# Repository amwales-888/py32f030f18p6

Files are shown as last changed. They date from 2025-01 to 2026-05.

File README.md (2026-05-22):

# py32f030f18p6
Simple breakout board for py32f030f18p6

- 3.3v LDO powered from 5V USB.
- UART connectivity to USB via ch340k optionally connected using jumpers.
- ARM SWD programming interface header.
- All other pins are broken out to headers.
- 1 LED optionally connected to pin PB5 using jumper.
- 1 Button optionally connected to pin PA8 using jumper.
- 1 Button connected to RESET pin, pulled high.
- Booloader selected by putting jumper across BOOT0 and 3v3 pins

<table>
  <tr>
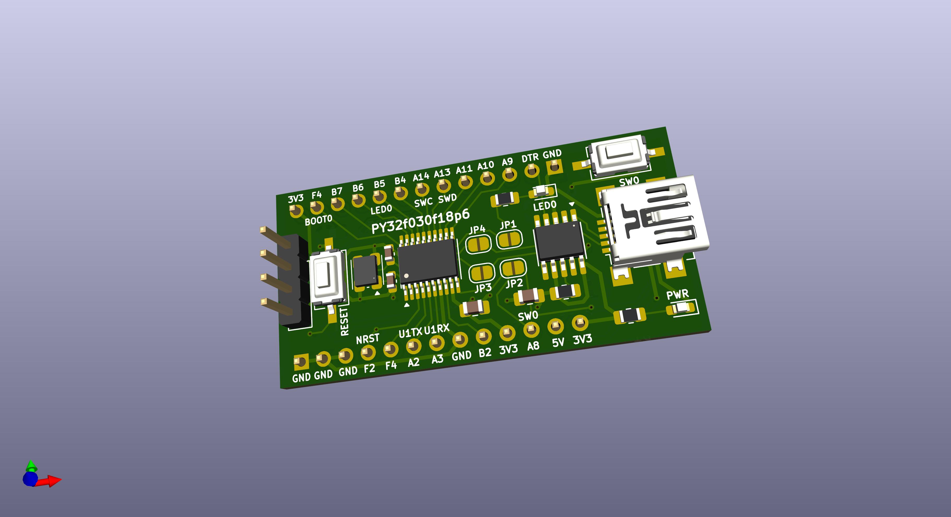
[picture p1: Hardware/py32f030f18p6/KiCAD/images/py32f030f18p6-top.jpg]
    <td> </td>
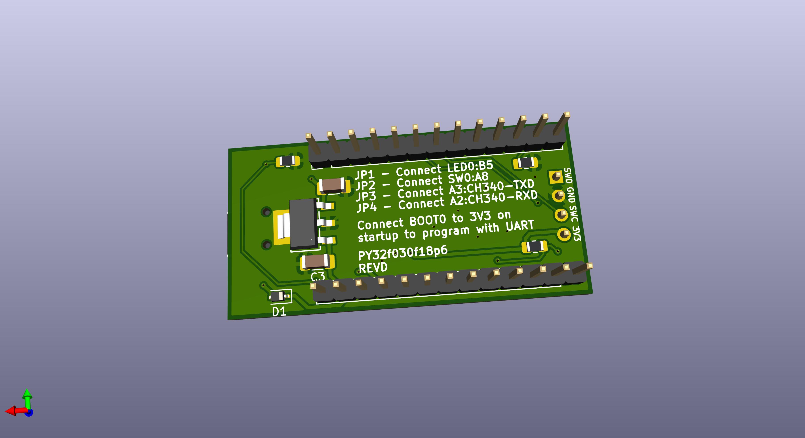
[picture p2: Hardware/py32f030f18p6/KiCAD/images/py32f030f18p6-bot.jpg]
    <td> </td>
  </tr>
  <tr>
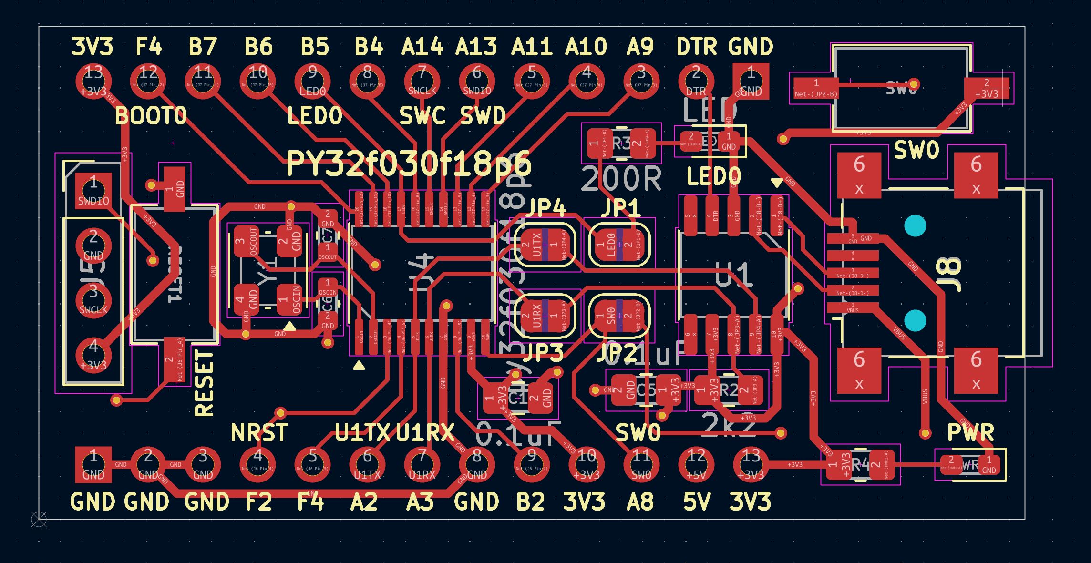
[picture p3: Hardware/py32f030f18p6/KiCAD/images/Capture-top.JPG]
    <td> </td>
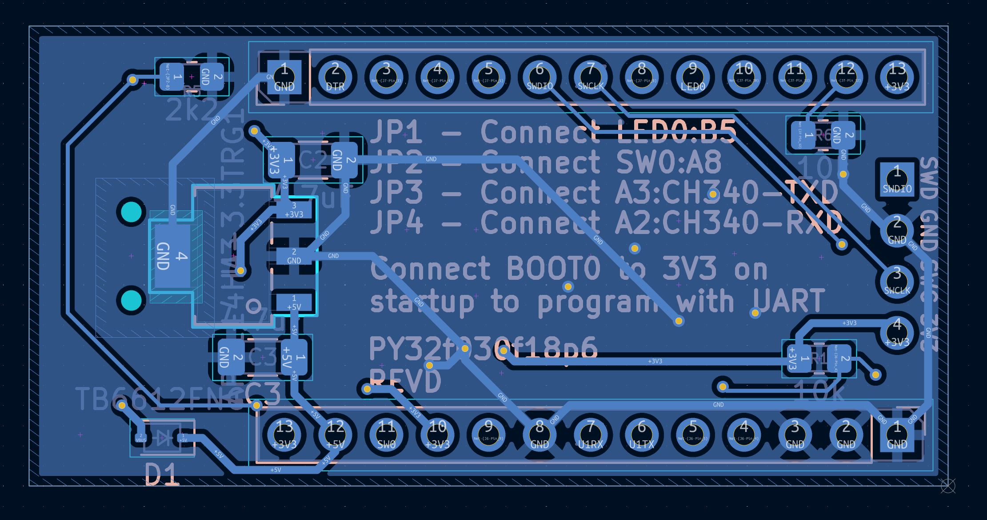
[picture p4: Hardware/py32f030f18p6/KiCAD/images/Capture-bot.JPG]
    <td> </td>
  </tr>
  <tr>
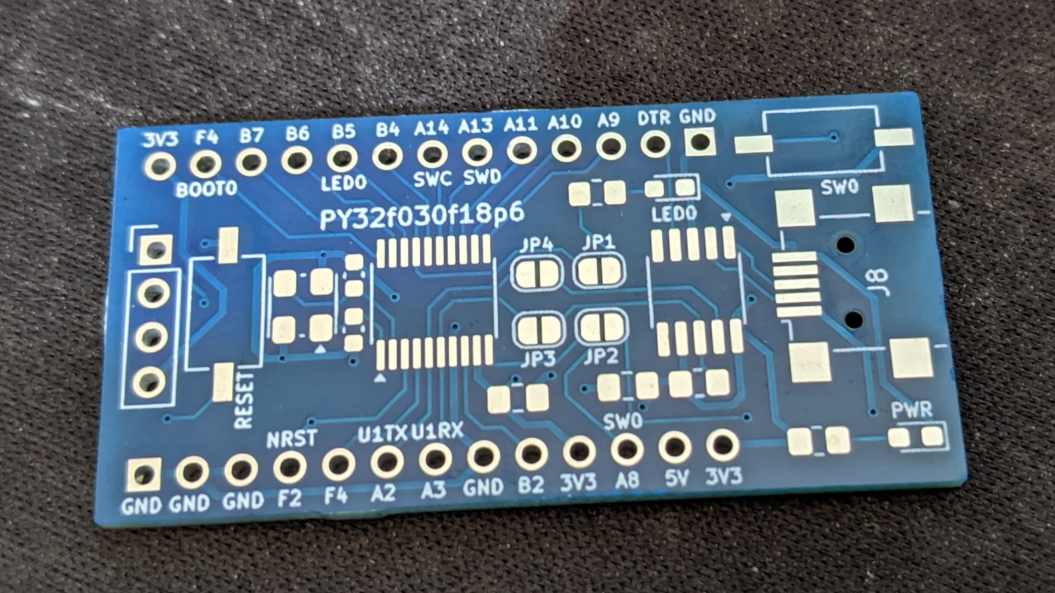
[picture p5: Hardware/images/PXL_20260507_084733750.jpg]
    <td> </td>
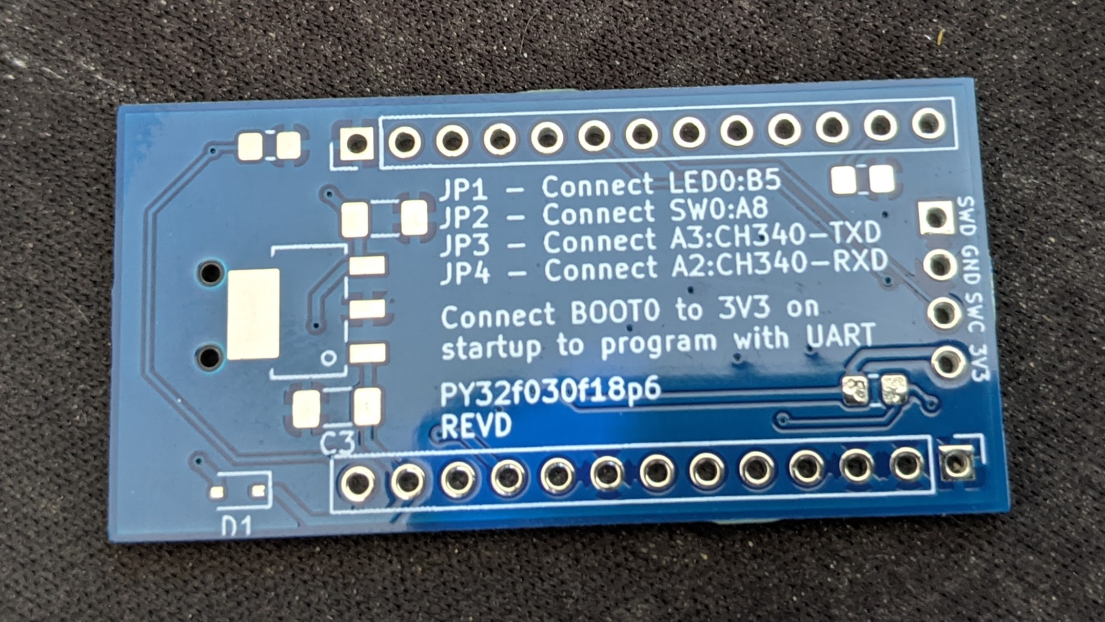
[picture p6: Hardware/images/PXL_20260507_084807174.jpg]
    <td> </td>
  </tr>
  <tr>
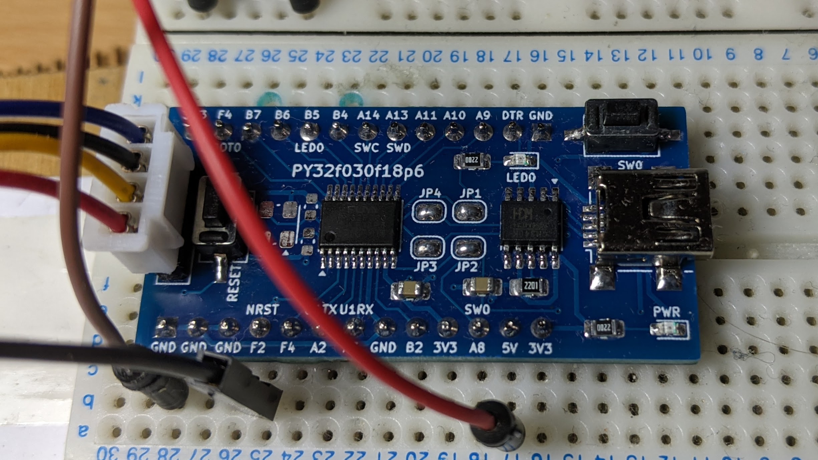
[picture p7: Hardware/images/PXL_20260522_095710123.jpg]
    <td> </td>
  </tr>
</table>

Resources

<li>https://www.puyasemi.com/en/py32_series.html</li>
<li>https://www.eevblog.com/forum/microcontrollers/$0-11-py32f002a-m0-24mhz-320kb-actually-324kb-more-peripherals/</li>
<li>https://www.cnblogs.com/milton/p/18168592</li>
<li>https://github.com/IOsetting/py32f0-template/tree/main</li>
<li>https://www.cnblogs.com/milton/p/17111286.html</li>
<li>https://www.cnblogs.com/milton/p/18168592</li>
<li>https://www.lcsc.com/product-detail/C3018715.html</li>

<BR>

Notes - Assembled board with 24Mhz crystal, flashed and tested with simple LED blink/UART code via the connected via USB. Used jlink clone connected via SWD and built with keil uvision, connected jlink to reset pin. Verified running at 48Mhz by timing blink rate of LED. Have not tested bootloader configuration yet.

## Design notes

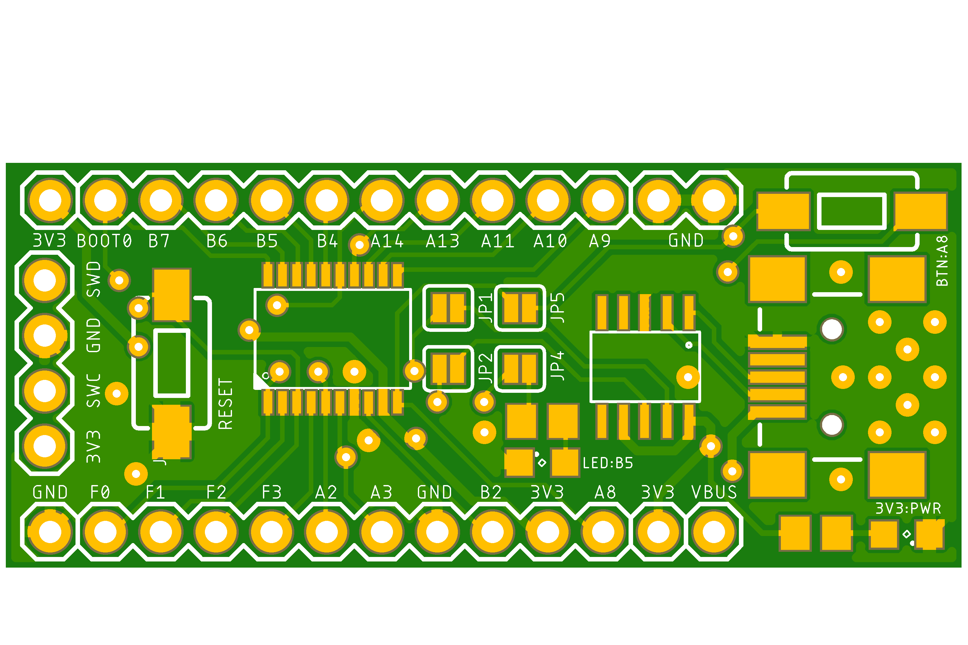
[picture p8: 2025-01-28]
Hardware/py32f030f18p6/Eagle/images/py32f030f18p6-Top.png

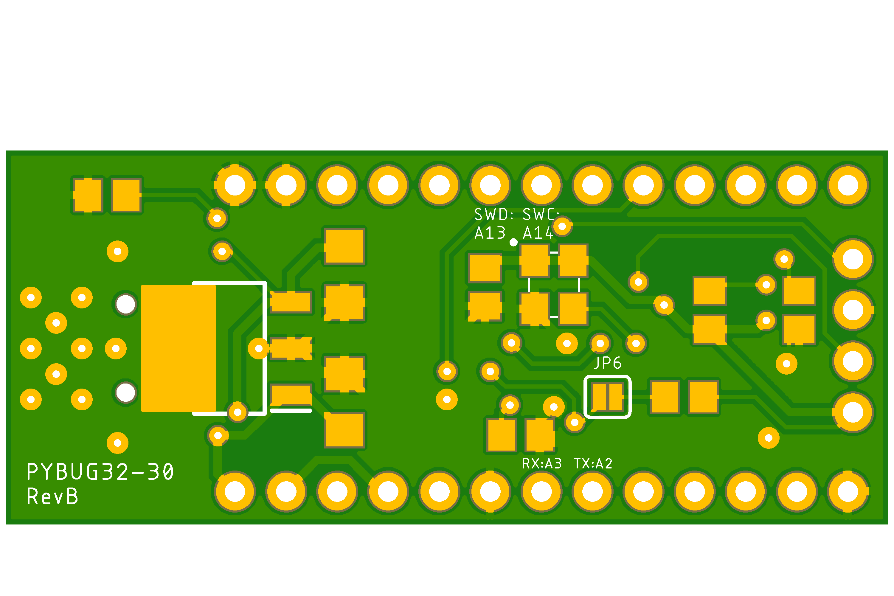
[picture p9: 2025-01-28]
Hardware/py32f030f18p6/Eagle/images/py32f030f18p6-Bot.png

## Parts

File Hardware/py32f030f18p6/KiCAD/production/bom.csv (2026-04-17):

Designator | Footprint | Quantity | Value | LCSC Part #
C1, C5 | 0805 | 2 | 0.1uF
C2, C3 | 1206 | 2 | 4.7uF
C6, C7 | 0603 | 2 | 18pF
D1 | D_SOD-323 | 1 | TB6612FNG
J5 | PinHeader_1x04_P2.54mm_Vertical | 1 | Conn_01x04_Pin
J6, J7 | PinHeader_1x13_P2.54mm_Vertical | 2 | Conn_01x13_Pin
J8 | USB_Mini-B_Lumberg_2486_01_Horizontal | 1 | USB_B_Mini
LED0, PWR1 | 0603 | 2 | LED
R1, R6 | 0805 | 2 | 10k
R2, R5 | 0805 | 2 | 2k2
R3, R4 | 0805 | 2 | 200R
RESET1, SW0 | SW_Tactile_SPST_NO_Straight_CK_PTS636Sx25SMTRLFS | 2 | SW_Push
U1 | SSOP-10-1EP_3.9x4.9mm_P1mm_EP2.1x3.3mm | 1 | CH340K
U3 | SOT-223_DIO | 1 | AP2114HA-3.3TRG1
U4 | TSSOP-20_4.4x6.5mm_P0.65mm | 1 | py32f030f18p6
Y1 | CDFN-4_2.5x3.2mm_P2.1mm | 1 | 16Mhz Crystal

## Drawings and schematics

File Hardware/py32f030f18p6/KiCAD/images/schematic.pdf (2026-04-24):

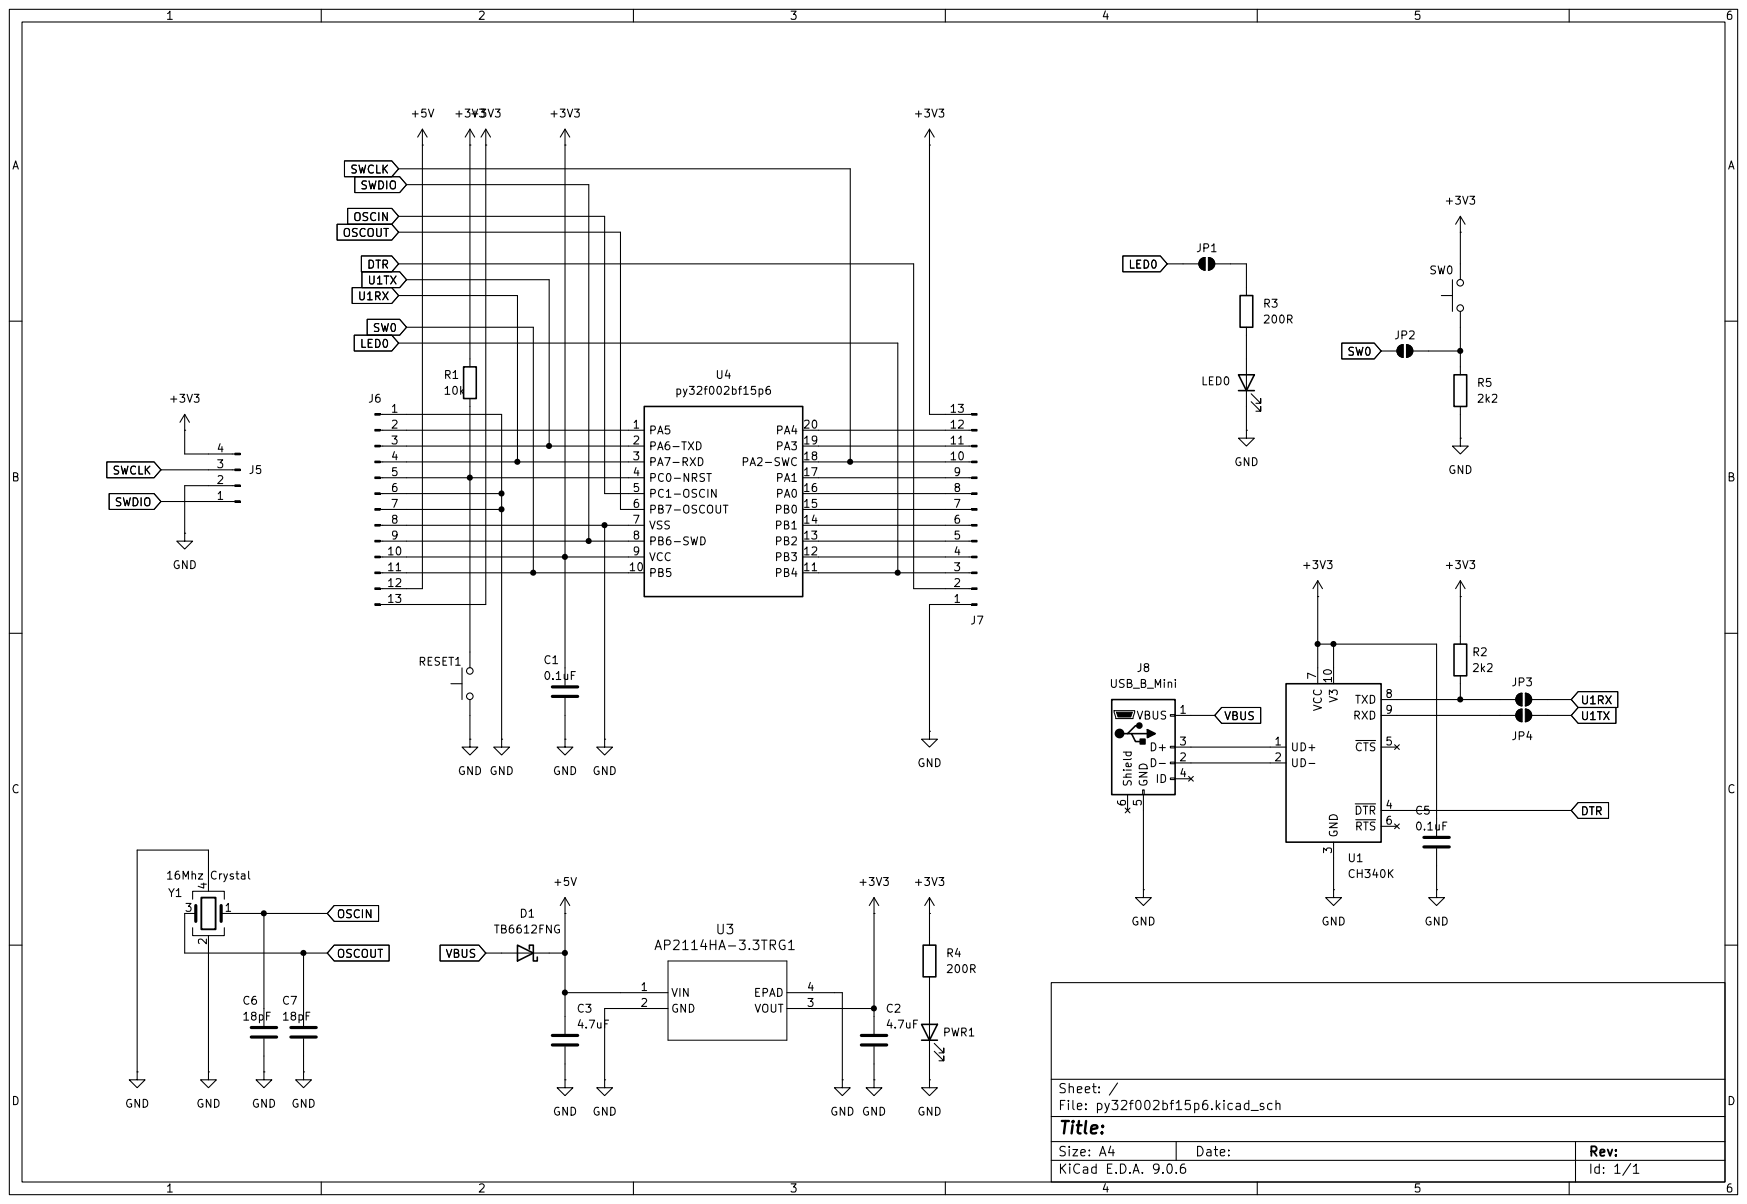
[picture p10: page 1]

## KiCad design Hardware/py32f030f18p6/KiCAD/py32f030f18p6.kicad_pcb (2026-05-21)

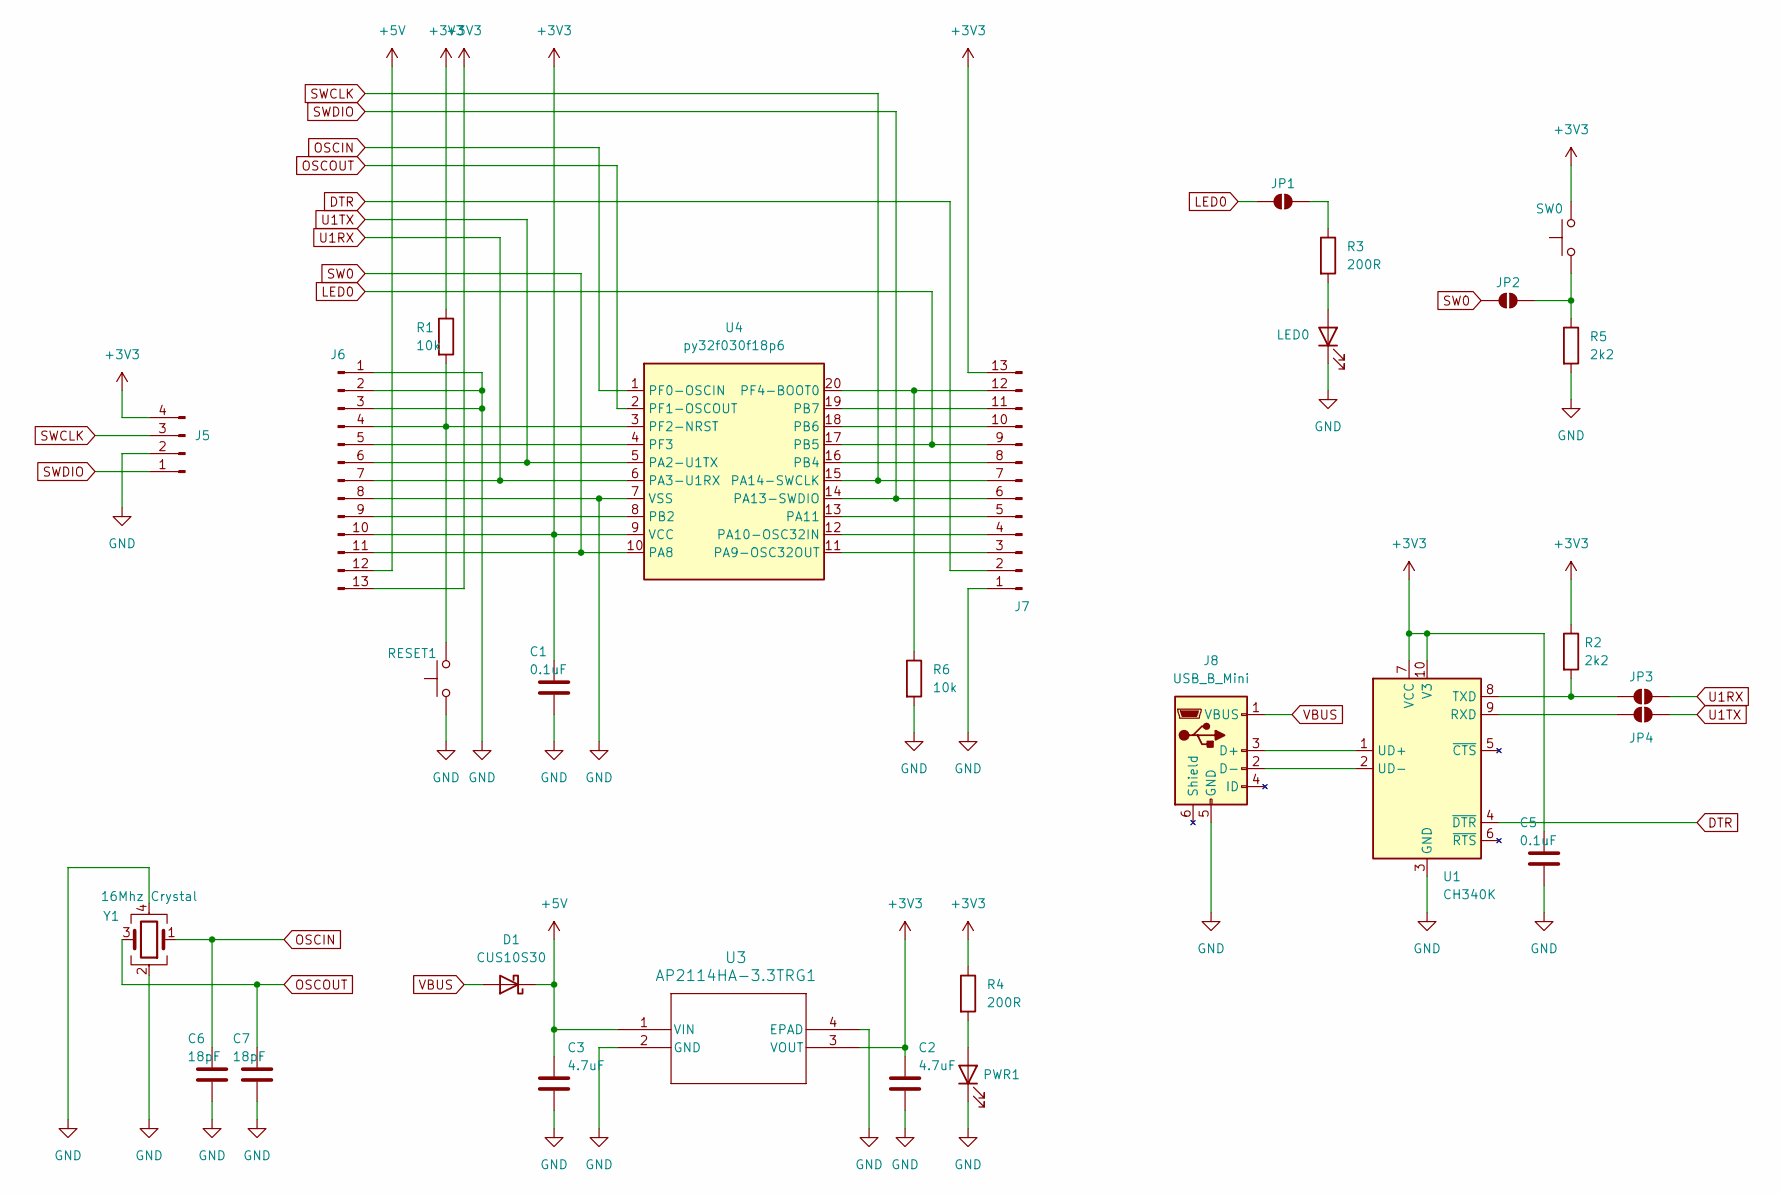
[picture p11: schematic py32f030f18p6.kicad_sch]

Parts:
C1, C5: 0.1uF; C_0805_2012Metric_Pad1.18x1.45mm_HandSolder
C2, C3: 4.7uF; C_1206_3216Metric_Pad1.33x1.80mm_HandSolder
C6, C7: 18pF; C_0603_1608Metric
D1: CUS10S30; D_SOD-323-H; LCSC Part# C146335
J5: Conn_01x04_Pin; PinHeader_1x04_P2.54mm_Vertical
J6, J7: Conn_01x13_Pin; PinHeader_1x13_P2.54mm_Vertical
J8: USB_B_Mini; USB_Mini-B_Lumberg_2486_01_Horizontal; LCSC Part# C105424
JP1, JP2, JP3, JP4: SolderJumper_2_Open; SolderJumper-2_P1.3mm_Open_RoundedPad1.0x1.5mm
LED0: LED; LED_0603_1608Metric_Pad1.05x0.95mm_HandSolder
PWR1: LED; LED_0603_1608Metric_Pad1.05x0.95mm_HandSolder
R1, R6: 10k; R_0805_2012Metric_Pad1.20x1.40mm_HandSolder
R2, R5: 2k2; R_0805_2012Metric_Pad1.20x1.40mm_HandSolder
R3, R4: 200R; R_0805_2012Metric_Pad1.20x1.40mm_HandSolder
RESET1: SW_Push; SW_Tactile_SPST_NO_Straight_CK_PTS636Sx25SMTRLFS
SW0: SW_Push; SW_Tactile_SPST_NO_Straight_CK_PTS636Sx25SMTRLFS
U1: CH340K; SSOP-10-1EP_3.9x4.9mm_P1mm_EP2.1x3.3mm; LCSC Part# C968586
U3: AP2114HA-3.3TRG1; SOT-223_DIO; LCSC Part# C460314
U4: py32f030f18p6; TSSOP-20_4.4x6.5mm_P0.65mm; LCSC Part# C3018715
Y1: 16Mhz Crystal; CDFN-4_2.5x3.2mm_P2.1mm; LCSC Part# C41383242

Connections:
+3V3: C1.1, C2.1, C5.1, J5.4, J6.10, J6.13, J7.13, R1.1, R2.1, R4.1, SW0.2, U1.7 (VCC), U1.10 (V3), U3.3 (VOUT), U4.9 (VCC)
+5V: C3.1, D1.1 (K), J6.12, U3.1 (VIN)
DTR: J7.2, U1.4 (~DTR)
GND: C1.2, C2.2, C3.2, C5.2, C6.2, C7.2, J5.2, J6.1, J6.2, J6.3, J6.8, J7.1, J8.5 (GND), LED0.1 (K), PWR1.1 (K), R5.2, R6.2, RESET1.1, U1.3 (GND), U3.2 (GND), U3.4 (EPAD), U4.7 (VSS), Y1.2, Y1.4
LED0: J7.9, JP1.1 (A), U4.17 (PB5)
unnamed: J6.4, R1.2, RESET1.2, U4.3 (PF2-NRST)
unnamed: J6.5, U4.4 (PF3)
unnamed: J6.9, U4.8 (PB2)
unnamed: J7.3, U4.11 (PA9-OSC32OUT)
unnamed: J7.4, U4.12 (PA10-OSC32IN)
unnamed: J7.5, U4.13 (PA11)
unnamed: J7.8, U4.16 (PB4)
unnamed: J7.10, U4.18 (PB6)
unnamed: J7.11, U4.19 (PB7)
unnamed: J7.12, R6.1, U4.20 (PF4-BOOT0)
unnamed: J8.3 (D+), U1.1 (UD+)
unnamed: J8.2 (D-), U1.2 (UD-)
unnamed: JP1.2 (B), R3.1
unnamed: JP2.2 (B), R5.1, SW0.1
unnamed: JP3.1 (A), R2.2, U1.8 (TXD)
unnamed: JP4.1 (A), U1.9 (RXD)
unnamed: LED0.2 (A), R3.2
unnamed: PWR1.2 (A), R4.2
OSCIN: C6.1, U4.1 (PF0-OSCIN), Y1.1
OSCOUT: C7.1, U4.2 (PF1-OSCOUT), Y1.3
SW0: J6.11, JP2.1 (A), U4.10 (PA8)
SWCLK: J5.3, J7.7, U4.15 (PA14-SWCLK)
SWDIO: J5.1, J7.6, U4.14 (PA13-SWDIO)
U1RX: J6.7, JP3.2 (B), U4.6 (PA3-U1RX)
U1TX: J6.6, JP4.2 (B), U4.5 (PA2-U1TX)
VBUS: D1.2 (A), J8.1 (VBUS)

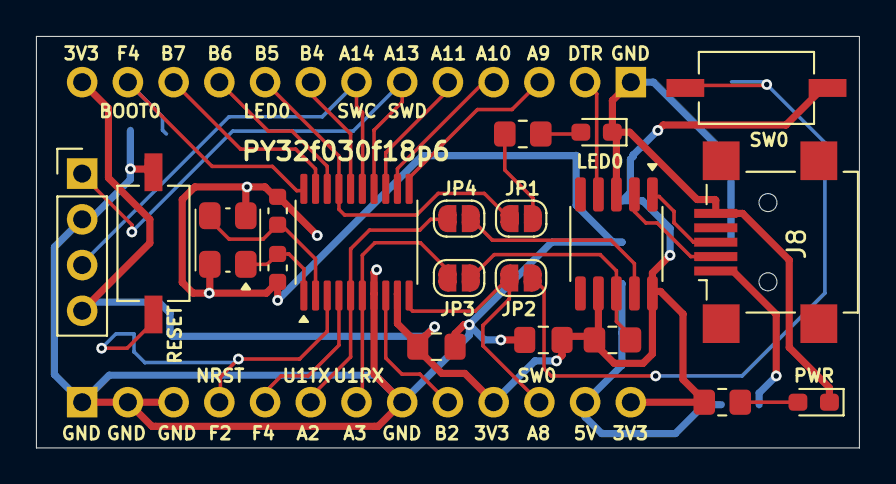
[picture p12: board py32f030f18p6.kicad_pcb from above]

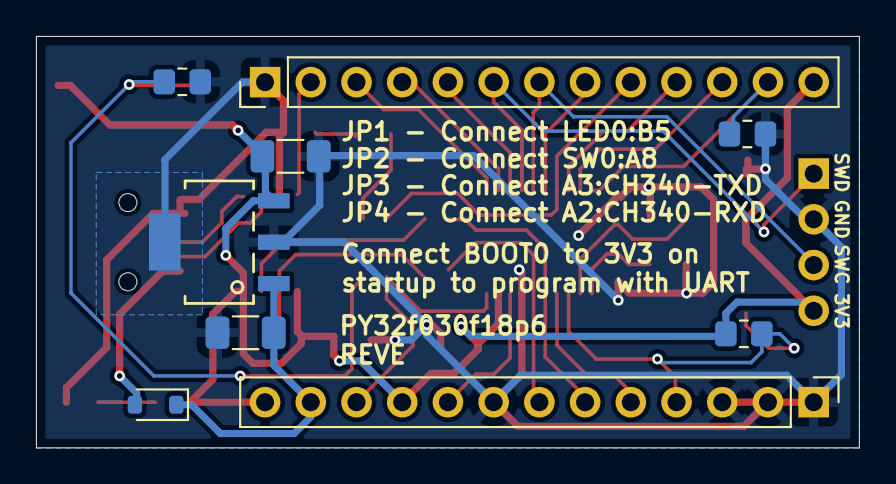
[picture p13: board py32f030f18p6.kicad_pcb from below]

Board: 2 copper layers, 45.7 x 22.9 mm, 29 parts (9 on the bottom side), 31 nets.

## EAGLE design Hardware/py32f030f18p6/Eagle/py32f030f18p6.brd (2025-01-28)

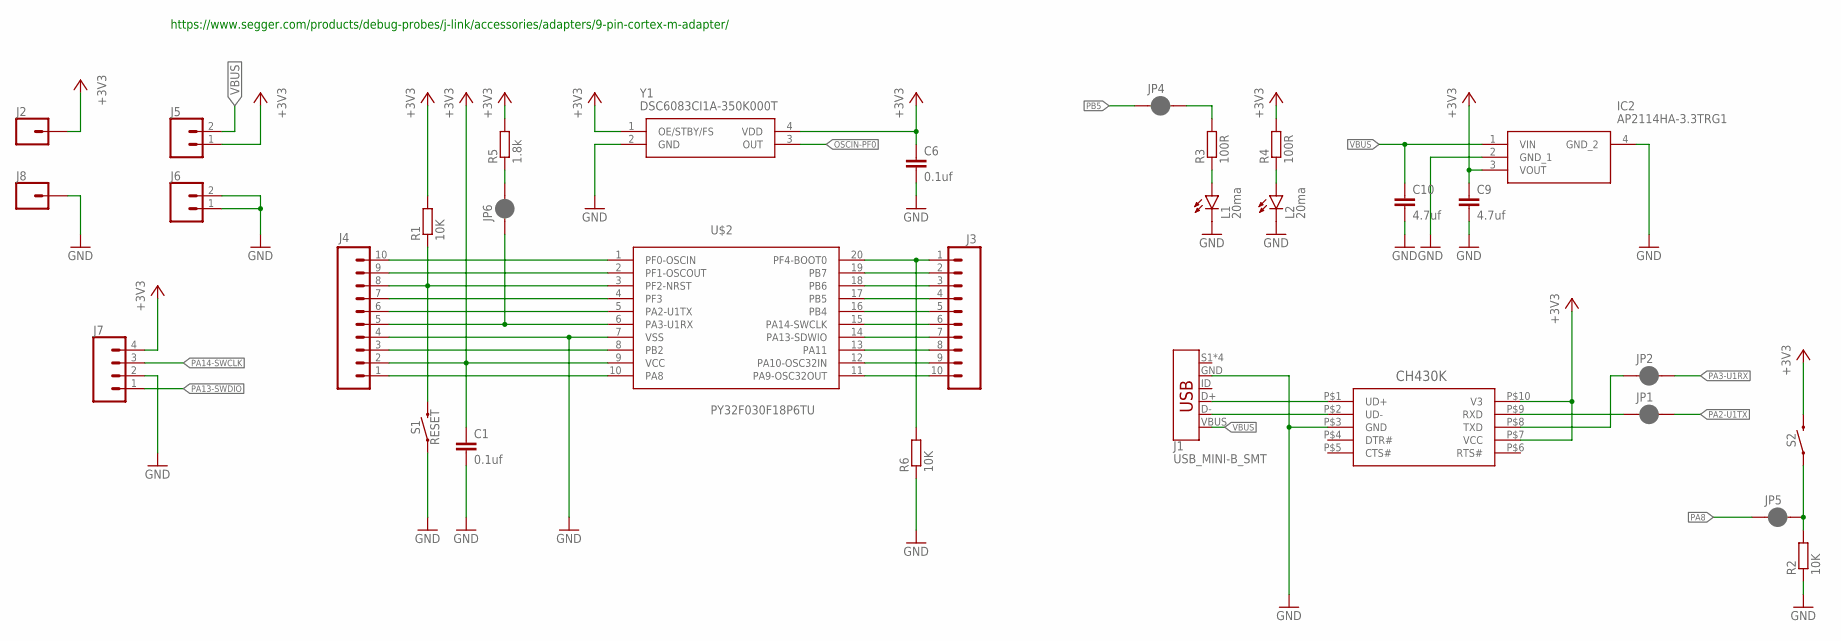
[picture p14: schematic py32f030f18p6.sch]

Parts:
C1, C6: 0.1uf; C0805
C9, C10: 4.7uf; C1206
IC2: AP2114HA-3.3TRG1; SOT230P700X180-4N
J1: USB_MINI-B_SMT; USB-MINIB
J2, J8: CONN_01; 1X01
J3, J4: CONN_10"; 1X10
J5, J6: CONN_02; 1X02
J7: CONN_04PTH; 1X04
JP1, JP2, JP4, JP5, JP6: JUMPER-SMT_2_NC_PASTE_SILK; SMT-JUMPER_2_NC_PASTE_SILK
L1, L2: 20ma; SML0805
R1, R2, R6: 10K; R0805
R3, R4: 100R; R0805
R5: 1.8k; R0805
S1, S2: RESET; TACTILE_SWITCH_SMD_6.0X3.5MM
U$1: CH430K; ESSOP-10
U$2: PY32F030F18P6TU; TSSOP20
Y1: DSC6083CI1A-350K000T; DSC6083CI1A350K000T

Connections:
+3V3: C1.1, C6.1, C9.1, IC2.3 (VOUT), J2.1, J4.2, J5.1, J7.4, R1.2, R4.2, R5.2, S2.2, U$1.P$7 (VCC), U$1.P$10 (V3), U$2.9 (VCC), Y1.1 (OE/STBY/FS), Y1.4 (VDD)
GND: C1.2, C6.2, C9.2, C10.2, IC2.2 (GND_1), IC2.4 (GND_2), J1.GND, J4.4, J6.1, J6.2, J7.2, J8.1, L1.C, L2.C, R2.1, R6.1, S1.1, U$1.P$3 (GND), U$2.7 (VSS), Y1.2 (GND)
unnamed: JP6.2, R5.1
unnamed: L1.A, R3.1
unnamed: JP4.2, R3.2
unnamed: JP5.2, R2.2, S2.1
unnamed: L2.A, R4.1
OSCIN-PF0: J4.10, U$2.1 (PF0-OSCIN), Y1.3 (OUT)
OSCOUT-PF1: J4.9, U$2.2 (PF1-OSCOUT)
PA2-U1TX: J4.6, JP1.2, U$2.5 (PA2-U1TX)
PA3-U1RX: J4.5, JP2.2, JP6.1, U$2.6 (PA3-U1RX)
PA8: J4.1, JP5.1, U$2.10 (PA8)
PA9-OSC32OUT: J3.10, U$2.11 (PA9-OSC32OUT)
PA10-OSC32IN: J3.9, U$2.12 (PA10-OSC32IN)
PA11: J3.8, U$2.13 (PA11)
PA13-SWDIO: J3.7, J7.1, U$2.14 (PA13-SDWIO)
PA14-SWCLK: J3.6, J7.3, U$2.15 (PA14-SWCLK)
PB2: J4.3, U$2.8 (PB2)
PB4: J3.5, U$2.16 (PB4)
PB5: J3.4, JP4.1, U$2.17 (PB5)
PB6: J3.3, U$2.18 (PB6)
PB7: J3.2, U$2.19 (PB7)
PF2-NRST: J4.8, R1.1, S1.2, U$2.3 (PF2-NRST)
PF3: J4.7, U$2.4 (PF3)
PF4-BOOT0: J3.1, R6.2, U$2.20 (PF4-BOOT0)
RXD: JP1.1, U$1.P$9 (RXD)
TXD: JP2.1, U$1.P$8 (TXD)
USB_N: J1.D-, U$1.P$2 (UD-)
USB_P: J1.D+, U$1.P$1 (UD+)
VBUS: C10.1, IC2.1 (VIN), J1.VBUS, J5.2

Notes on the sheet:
https://www.segger.com/products/debug-probes/j-link/accessories/adapters/9-pin-cortex-m-adapter/

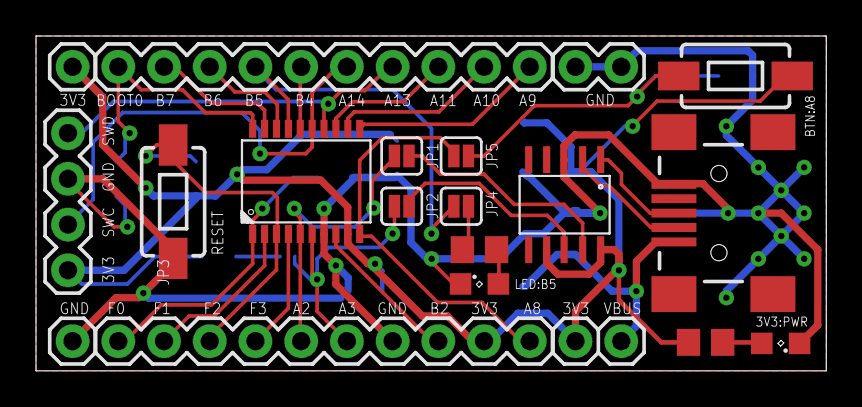
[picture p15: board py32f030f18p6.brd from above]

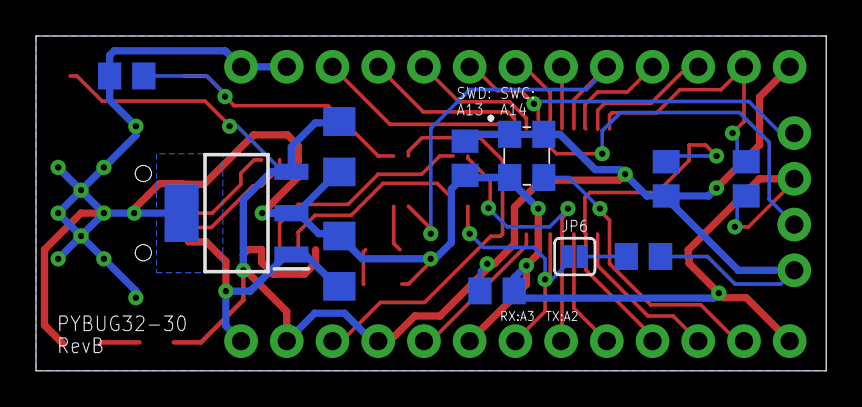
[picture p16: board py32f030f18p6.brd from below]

Board: 2 copper layers, 43.9 x 18.6 mm, 31 parts (11 on the bottom side), 30 nets.

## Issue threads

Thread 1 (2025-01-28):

Not really an issue ;-) ::   I would like to know if you build a test board successfully ?

demoze, 2025-01-28:
HEllo,

Not really an issue ;-)

I would like to know if you build a test board successfully ?

Regards

amwales-888, 2025-01-28:
The board that is currently published and tagged as py32f030f18p6_2024-09-27_Y18 has an issue.
The RX pin needs a 1.8k pullup resistor so that the builtin firmware bootloader will work.
I have made the corrections locally that I have not pushed up to github.
I had boards manufactured and had to hand solder the pullup.
I will make a new release shortly that has the fix.

amwales-888, 2025-01-28:
Fixes have been integrated and tagged as py32f030f18p6-revb

Closed 2025-01-28.

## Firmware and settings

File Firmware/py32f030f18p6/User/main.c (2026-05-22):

/**
  ******************************************************************************
  * @file    main.c
  * @author  MCU Application Team
  * @brief   Main program body
  ******************************************************************************
  * @attention
  *
  * <h2><center>&copy; Copyright (c) Puya Semiconductor Co.
  * All rights reserved.</center></h2>
  *
  * <h2><center>&copy; Copyright (c) 2016 STMicroelectronics.
  * All rights reserved.</center></h2>
  *
  * This software component is licensed by ST under BSD 3-Clause license,
  * the "License"; You may not use this file except in compliance with the
  * License. You may obtain a copy of the License at:
  *                        opensource.org/licenses/BSD-3-Clause
  *
  ******************************************************************************
  */

#include "main.h"
#include "py32f0xx_ll_gpio.h"
#include "py32f0xx_ll_usart.h"

#define USE24MHZCRYSTAL

static void APP_SystemClockConfig(void);
static void APP_GPIOConfig(void);
static void APP_ConfigUsart(USART_TypeDef *USARTx);
//static int APP_UsartReceiveByte(USART_TypeDef *USARTx, uint8_t *ptr);
static int APP_UsartSendByte(USART_TypeDef *USARTx, uint8_t b);

static void outputMessage(void) {

	static uint8_t *msg = (uint8_t *)"hello world\r\n";
	static uint8_t i = 0;
	
	if (APP_UsartSendByte(USART1, msg[i]) != 0) {
		i++;
		if (msg[i] == '\0') {
			i = 0;
		}
	}	
}

int main(void)
{
  APP_SystemClockConfig();
  APP_GPIOConfig();
	
	APP_ConfigUsart(USART1);
		
  while (1)
  {
		outputMessage();
    LL_GPIO_TogglePin(GPIOB, LL_GPIO_PIN_5);
    LL_mDelay(1000);
  }
}

static void APP_SystemClockConfig(void)
{
#ifdef USE24MHZCRYSTAL
	LL_UTILS_ClkInitTypeDef UTILS_ClkInitStruct;
	LL_RCC_HSI_Enable();
	LL_RCC_HSE_SetFreqRegion(LL_RCC_HSE_16_32MHz);

	while(LL_RCC_HSI_IsReady() != 1);

	UTILS_ClkInitStruct.AHBCLKDivider = LL_RCC_SYSCLK_DIV_1;
	UTILS_ClkInitStruct.APB1CLKDivider = LL_RCC_APB1_DIV_1;
	LL_PLL_ConfigSystemClock_HSE(24000000U, LL_UTILS_HSEBYPASS_OFF, &UTILS_ClkInitStruct);

	/* Re-init frequency of SysTick source, reload = freq/ticks = 48000000/1000 = 48000 */
	LL_InitTick(48000000, 1000U);	
#else
  LL_RCC_HSI_Enable();
  while(LL_RCC_HSI_IsReady() != 1);

  LL_RCC_SetAHBPrescaler(LL_RCC_SYSCLK_DIV_1);
  LL_RCC_SetSysClkSource(LL_RCC_SYS_CLKSOURCE_HSISYS);
  while(LL_RCC_GetSysClkSource() != LL_RCC_SYS_CLKSOURCE_STATUS_HSISYS);

  LL_RCC_SetAPB1Prescaler(LL_RCC_APB1_DIV_1);
  LL_Init1msTick(8000000);
  LL_SetSystemCoreClock(8000000);
#endif
}


static void APP_GPIOConfig(void)
{
  LL_IOP_GRP1_EnableClock(LL_IOP_GRP1_PERIPH_GPIOB);
  LL_GPIO_SetPinMode(GPIOB, LL_GPIO_PIN_5, LL_GPIO_MODE_OUTPUT);
}

void APP_ErrorHandler(void)
{
  while (1);
}

#ifdef  USE_FULL_ASSERT
void assert_failed(uint8_t *file, uint32_t line)
{
  while (1);
}
#endif /* USE_FULL_ASSERT */


static void APP_ConfigUsart(USART_TypeDef *USARTx)
{
  if (USARTx == USART1) 
  {
    LL_IOP_GRP1_EnableClock(LL_IOP_GRP1_PERIPH_GPIOA);
    LL_APB1_GRP2_EnableClock(LL_APB1_GRP2_PERIPH_USART1);
    
    LL_GPIO_InitTypeDef GPIO_InitStruct;
    GPIO_InitStruct.Pin = LL_GPIO_PIN_2;
    GPIO_InitStruct.Mode = LL_GPIO_MODE_ALTERNATE;
    GPIO_InitStruct.Speed = LL_GPIO_SPEED_FREQ_VERY_HIGH;
    GPIO_InitStruct.OutputType = LL_GPIO_OUTPUT_PUSHPULL;
    GPIO_InitStruct.Pull = LL_GPIO_PULL_UP;
    GPIO_InitStruct.Alternate = LL_GPIO_AF1_USART1;
    LL_GPIO_Init(GPIOA,&GPIO_InitStruct);
    
    GPIO_InitStruct.Pin = LL_GPIO_PIN_3;
    GPIO_InitStruct.Alternate = LL_GPIO_AF1_USART1;
    LL_GPIO_Init(GPIOA,&GPIO_InitStruct);
  }
  else if (USARTx == USART2)
  {
    LL_IOP_GRP1_EnableClock(LL_IOP_GRP1_PERIPH_GPIOA);
    LL_APB1_GRP1_EnableClock(LL_APB1_GRP1_PERIPH_USART2);
    
    LL_GPIO_InitTypeDef GPIO_InitStruct;
    GPIO_InitStruct.Pin = LL_GPIO_PIN_2;
    GPIO_InitStruct.Mode = LL_GPIO_MODE_ALTERNATE;
    GPIO_InitStruct.Speed = LL_GPIO_SPEED_FREQ_VERY_HIGH;
    GPIO_InitStruct.OutputType = LL_GPIO_OUTPUT_PUSHPULL;
    GPIO_InitStruct.Pull = LL_GPIO_PULL_UP;
    GPIO_InitStruct.Alternate = LL_GPIO_AF4_USART2;
    LL_GPIO_Init(GPIOA,&GPIO_InitStruct);
    
    GPIO_InitStruct.Pin = LL_GPIO_PIN_3;
    GPIO_InitStruct.Alternate = LL_GPIO_AF4_USART2;
    LL_GPIO_Init(GPIOA,&GPIO_InitStruct);
  }
  
  LL_USART_InitTypeDef USART_InitStruct;
  USART_InitStruct.BaudRate = 9600;
  USART_InitStruct.DataWidth = LL_USART_DATAWIDTH_8B;
  USART_InitStruct.StopBits = LL_USART_STOPBITS_1;
  USART_InitStruct.Parity = LL_USART_PARITY_NONE;
  USART_InitStruct.TransferDirection = LL_USART_DIRECTION_TX_RX;
  USART_InitStruct.HardwareFlowControl = LL_USART_HWCONTROL_NONE;
  USART_InitStruct.OverSampling = LL_USART_OVERSAMPLING_16;
  LL_USART_Init(USARTx, &USART_InitStruct);
  
  LL_USART_ConfigAsyncMode(USARTx);
  
  LL_USART_Enable(USARTx);
}


//static int APP_UsartReceiveByte(USART_TypeDef *USARTx, uint8_t *ptr) {
//	
//	if (LL_USART_IsActiveFlag_RXNE(USARTx) == 1) {
//		*ptr = LL_USART_ReceiveData8(USARTx);
//		return 1;
//	}
//	
//	return 0;
//}

static int APP_UsartSendByte(USART_TypeDef *USARTx, uint8_t b) {
	
	if (LL_USART_IsActiveFlag_TXE(USARTx) == 1) {		
		LL_USART_TransmitData8(USARTx, b);
		return 1;
	}
	
	return 0;
}

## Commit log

2024-09-23 Initial checkin
    [py32f030f18p6.brd, py32f030f18p6.sch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]
2024-09-26 Remove button replace with header, removed reset pin
    Replaced the boot button with a header, removed reset pin
    [py32f030f18p6.brd, py32f030f18p6.sch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]
2024-09-27 Generate latest gerbers
    [copper_bottom.gbr, copper_top.gbr, drill_1_16.xln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]
2024-09-29 Added led blink firmware
    Added eaxmple led blink firmware, the resulting .hex file can be flashed to the board by plugging in the USB enabling the bootloader pins, running the PY32_IspTool connecting and downloading.
2024-10-24 blink portb pin5 thats connected to a led
2025-01-28 Added missing pullup on RX to fix bootloader issue, updated the firmware so it outputs message on uart
    [py32f030f18p6.brd, py32f030f18p6.sch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]
2025-01-28 Issue with silk screen, GND pin was labelled 3v3
    [py32f030f18p6.brd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]
2026-04-17 Reformat Directory Structure and Add KiCAD version
    Reformat Directory Structure and Add KiCAD version
    [bom.csv, designators.csv, positions.csv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]
2026-04-24 Deprecated old eagle layout
    Deprecated old eagle layout
    [py32f030f18p6.brd, py32f030f18p6.sch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]
2026-04-25 Update README with firmware notes
    Add notes regarding firmware and board changes.
2026-05-21 Updated firmware, changed pad size on diode to make more hand solder friendly
    Build board and verified blink led on latest board back from jlpcb, programmed with swd using reset pin, changed pad size for diode as it was tiny.
    [py32f030f18p6.kicad_pcb, py32f030f18p6.kicad_sch]
2026-05-22 Revise notes on board assembly and testing process
    Updated notes section to reflect changes in board assembly and testing.
2026-05-22 Revise assembly notes for board configuration
    Updated notes to reflect the addition of a 24MHz crystal and verification of 48MHz operation.

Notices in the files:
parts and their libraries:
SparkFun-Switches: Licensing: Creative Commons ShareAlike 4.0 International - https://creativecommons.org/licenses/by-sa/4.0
